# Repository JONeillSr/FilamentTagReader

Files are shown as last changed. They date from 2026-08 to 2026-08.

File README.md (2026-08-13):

# Filament Tag Reader / Writer

An ESP32 + MFRC522 (RC522 / HW-126) reader/writer for **3D-printer filament spool
NFC tags**. It reads and writes multiple tag standards &mdash; **Anycubic**,
**OpenSpool**, and **TigerTag** &mdash; auto-detecting the format on read and
writing whichever format you select. Filament data (type, brand, color,
temperatures, diameter, weight) is shown on a 0.96" SSD1306 OLED and a web
dashboard, and new tags are written from a web form with read-back verification.
A common-cathode tri-color LED and active buzzer give immediate read/write
feedback.

Built from a set of self-contained, application-agnostic modules (board config,
event bus, WiFi provisioning, web service, display, RFID, feedback, and a
pluggable tag-format layer) so each one can be lifted into another ESP32 project
unchanged.

---

## Features

- **Multi-format support** &mdash; reads and writes three filament-tag standards
  through one pluggable interface:
  - **Anycubic** &mdash; the native NTAG21x binary page format (SKU, brand, type,
    color, nozzle/bed temps, diameter, length).
  - **OpenSpool** &mdash; an NDEF/JSON record on NTAG215/216 (type, color, brand,
    single temp range); the simplest cross-tool standard.
  - **TigerTag** &mdash; a big-endian binary structure on NTAG213 using numeric
    material/brand/aspect IDs; read by printers such as the Snapmaker U1.
- **Auto-detect on read** &mdash; tap any tag and the device identifies its format
  (Anycubic header magic, OpenSpool NDEF marker, or TigerTag version field) and
  decodes it. No need to pre-select.
- **Format-aware writes** &mdash; pick the write format on `/setup`; the dashboard
  shows the active format. Writes are read back and **byte-verified** before
  reporting success.
- **Read / write mode** toggled live on the dashboard or set as a persistent
  default on `/setup`.
- **Editable lookup tables** in flash, with browser editors (validated before
  saving, with built-in fallbacks): Anycubic filament definitions (`/filaments`)
  and the TigerTag ID database (`/tigertag`).
- **Color converter** on the write panel: enter HEX, RGB, ABGR, or RGBA and the
  others update live &mdash; each hex form matches the byte order its format
  stores (Anycubic ABGR, TigerTag RGBA).
- **Web dashboard** (`/`) showing all fields, with the filament color rendered
  as a colored circle.
- **Status page** (`/status`) with module health, last UID, write format, and
  last result &mdash; themed, with a dashboard link.
- **WebSerial** (`/webserial`) + telnet (port 23) live diagnostic log &mdash;
  essential because the ESP32-C6 drops USB serial on reboot.
- OTA updates (`/update`) via ElegantOTA.
- WiFi captive-portal provisioning (no hardcoded credentials).
- mDNS: reachable at `http://filament.local`.
- Fully event-driven, FreeRTOS task separation, **no blocking `delay()`**.

---

## Supported boards

Build one environment per board (`platformio.ini`):

| Board | Env | Notes |
|---|---|---|
| Seeed XIAO ESP32-C6 | `xiao_c6` | Primary target. Single I2C bus only. |
| ESP32-C3 devkit | `esp32c3` | Tight GPIO budget. |
| ESP32-S3 devkitc-1 | `esp32s3` | GPIO-rich. |
| Classic ESP32 DevKit | `esp32dev` | Serial survives reboot (watchable). |

```
pio run -e xiao_c6
pio run -e xiao_c6 -t upload
```

Uses the **pioarduino** fork of the espressif32 platform (required for current
ESP32-C6 / Arduino-ESP32 3.x support).

---

## Hardware wiring

OLED is SSD1306, I2C address `0x3C`, on the board's default I2C pins (shared
`Wire` bus &mdash; `Wire1` is avoided per the C6 core bug #10685). RC522 uses
hardware SPI. RGB LED is common-cathode (each leg lit HIGH); active buzzer
sounds when driven HIGH.

Exact GPIO assignments per board live in `src/Pins.h`, chosen to avoid each
board's strapping / flash / USB pins (documented in `lib/BoardConfig`).

### Classic ESP32 DevKit V1 (first bring-up)

Wiring for the `esp32dev` environment, matching the project wiring diagram:

| Function | GPIO | Notes |
|---|---|---|
| OLED SDA | 21 | shared I2C bus |
| OLED SCL | 22 | shared I2C bus |
| RC522 SDA/SS| 17 | VSPI CS |
| RC522 SCK | 18 | VSPI SCK |
| RC522 MOSI  | 23 | VSPI MOSI |
| RC522 MISO  | 19 | VSPI MISO |
| RC522 RST | 4 | plain GPIO |
| Buzzer SPK+ | 13 | SPK- to GND |
| LED Red | 25 | common cathode |
| LED Green | 26 | common cathode |
| LED Blue | 27 | common cathode |

> The RC522 runs on **3.3V** &mdash; it is not 5V-tolerant. If the version
> register reads erratically under load, add a 100&micro;F cap across the
> module's 3.3V / GND pins to absorb inrush.

### XIAO ESP32-C6

| Function | GPIO |
|---|---|
| OLED SDA | 22 |
| OLED SCL | 23 |
| RC522 SCK | 19 |
| RC522 MISO  | 20 |
| RC522 MOSI  | 18 |
| RC522 SS | 17 |
| RC522 RST | 16 |
| Buzzer | 1 |
| LED R | 2 |
| LED G | 21 |
| LED B | 0 |

> See `src/Pins.h` for the C3 / S3 maps.

---

## Tag formats

The device understands three filament-tag standards through a common
`TagFormat` interface. On **read**, each format's detector is tried against the
raw bytes and the matching one decodes; on **write**, the format selected on
`/setup` is used. All three translate to/from one neutral `FilamentRecord`, so
the dashboard, OLED, and feedback are format-independent.

| Format | Chip | Encoding | Detected by |
|---|---|---|---|
| Anycubic  | NTAG21x | binary pages, LE | header magic `0x7B` at page 4  |
| OpenSpool | NTAG215/216 | NDEF + JSON | NDEF record + `openspool` marker |
| TigerTag  | NTAG213 | binary struct, BE | version field at page 4 |

### Anycubic

NTAG21x (4 bytes per page). Multi-byte numbers are **little-endian**; strings are
NUL-padded ASCII across their page range.

| Page  | Example | Field |
|---|---|---|
| 4 | `7B 00 65 00`| header (magic `0x7B` / length) &mdash; not decoded |
| 5&ndash;8 | ASCII  | **SKU** &rarr; `AHPLLB-103` |
| 10&ndash;13 | ASCII  | **Brand** &rarr; `AC` (Anycubic) |
| 15&ndash;18 | ASCII  | **Type** &rarr; `PLA` |
| 20 | `FF 00 FF 00`| **Color**, ABGR byte order &rarr; `#00FF00` |
| 24 | `C8 00 D2 00`| **Extruder temp** min/max &rarr; 200&ndash;210 &deg;C |
| 29 | `32 00 3C 00`| **Bed temp** min/max &rarr; 50&ndash;60 &deg;C |
| 30 | `AF 00 4A 01`| **Diameter** (`175`/100 = 1.75 mm), **Length** raw `330` |
| 31 | `E8 03 00 00`| unknown (`1000`) &mdash; not decoded |

**Color note:** page 20 is decoded as ABGR (bytes A, B, G, R). The example
`FF 00 FF 00` therefore yields R=0, G=255, B=0 = **green `#00FF00`**, *not*
magenta. If real spools show the wrong swatch, the byte order is the first
thing to revisit.

**Length note:** `lengthRaw` (e.g. `330`) is surfaced raw; its exact units
(meters vs a packed value) are unconfirmed and shown as-is.

Writing touches only the pages this format defines (4, 5&ndash;8, 10&ndash;13,
15&ndash;18, 20, 24, 29&ndash;31); lock and configuration pages are left
untouched.

### OpenSpool

A single NDEF record of MIME type `application/json` on NTAG215/216, wrapped in
the NTAG NDEF-message TLV. The payload is human-readable:

```
{ "protocol":"openspool", "version":"1.0", "type":"PLA",
  "color_hex":"FFAABB", "brand":"Generic",
  "min_temp":"220", "max_temp":"240" }
```

Brands are constrained to the OpenSpool set (Generic, Overture, PolyLite, eSun,
PolyTerra); unknown brands write as `Generic`. OpenSpool carries a single
(nozzle) temp range; bed temps are not part of the standard.

### TigerTag

A fixed **big-endian** binary structure on NTAG213, pages 4&ndash;23 (80 bytes);
pages 24&ndash;39 hold an optional ECDSA signature that this firmware does not
read or write (basic read/write scope). Material, brand, and finish ("aspect")
are stored as **numeric IDs** from the TigerTag database rather than text.

| Bytes (from page 4) | Field |
|---|---|
| 0&ndash;3 | ID TigerTag (format/version) |
| 4&ndash;7 | ID Product (`FFFFFFFF` for Maker tags) |
| 8&ndash;9 | Material ID |
| 10 | Diameter ID (`0x38`=1.75, `0xDD`=2.85) |
| 11&ndash;12 | Aspect 1 / 2 (finish) |
| 13 | Type (`0x8E`=Filament) |
| 14&ndash;15 | Brand ID |
| 16 | Unit (`0x15`=g) |
| 17&ndash;20 | Color1 RGBA |
| 29&ndash;31 | Weight (grams) |
| 32&ndash;37 | Nozzle min/max, dry temp/time, bed min/max |
| 38&ndash;41 | Timestamp (also twin-tag pairing ID) |
| 54&ndash;79 | Custom message (up to 26 bytes) |

The numeric IDs are resolved via `data/tigertag_ids.json` (the official TigerTag
database, brand/material/aspect &rarr; ID), with an alias layer that maps common
local naming (e.g. `Matte` &rarr; `Matt`, `PLA` + `High Speed` &rarr; the
`PLA High Speed` material) onto the official IDs. Brands not in the database
write as Generic, with the real brand name kept in the custom-message field.

> **Note:** implemented purely from the public TigerTag specification (not their
> GPLv3 code) to keep this project's MIT license clean. "TigerTag" is referenced
> only as a supported format name, per their trademark policy.

All three codecs are **bidirectional**: a tag written by this device reads back
identically, and each `encode()` is the inverse of its `decode()`.

---

## Reading and writing

The device runs in one of two modes, shown in the dashboard header:

- **Read** (default) &mdash; a tap auto-detects the tag's format and shows the
  decoded spool (including which format it was) on the OLED and dashboard.
- **Write** &mdash; the **Write a spool tag** panel appears (with the active
  write format shown as a badge). Pick a material, color, and weight, then
  **Write tag** and tap. The device encodes the record in the selected format,
  writes it, reads it back, and only reports success if every written page
  verifies.

Toggle the mode live from the dashboard, or set a persistent power-on default on
`/setup`. The **write format** (Anycubic / OpenSpool / TigerTag) is also chosen
on `/setup` and shown on `/status`. Material temps and brand are filled in
automatically for the chosen material; color comes from the picker; weight maps
to the format's weight/length field.

### Color converter

The write panel includes a four-way color converter: enter a value as **HEX**,
**RGB**, **ABGR**, or **RGBA** and the others update live; picking a color in the
color picker updates the boxes too. Each hex form uses the byte order its format
stores &mdash; ABGR for Anycubic, RGBA for TigerTag &mdash; so it doubles as a
tool for cross-checking raw tag bytes. **Use** sets the write color from the
converter.

### Lookup tables

Two editable JSON tables live in the flash filesystem:

- **`data/filaments.json`** (editable at **`/filaments`**) &mdash; Anycubic
  material definitions: extruder/bed temps, SKU, brand, and a weight&rarr;length
  map.
- **`data/tigertag_ids.json`** (editable at **`/tigertag`**) &mdash; the TigerTag
  brand/material/aspect ID database plus the local-naming alias layers.

Both have a browser editor (linked from the dashboard header) with the same
validated-save behavior. Edits are written straight to LittleFS, so adding a
brand or fixing a mapping no longer needs a re-flash.

Edits are validated before saving &mdash; malformed JSON is rejected and the
previous table kept &mdash; and small built-in fallback sets are used if a file
is missing or invalid (the fallback state is surfaced on `/status`).

### Read / write feedback

| Outcome | LED | Buzzer |
|---|---|---|
| Good read | green | two short beeps |
| Good write | blue  | two short beeps |
| Bad read/write | red | one long beep |

The OLED "Write OK" screen also shows which format was written.

> A hardware mode button is a planned option; for now the mode is set from the
> web UI.

---

## Architecture

Event-driven with FreeRTOS task separation. In read mode the reader task decodes
a tag and pushes an `AppEvent`; in write mode it writes the queued record and
verifies it, pushing a write-result event. A dispatcher task consumes the queue
and updates the OLED, LED/buzzer, and logs.

```
[RFIDReader task] read mode  --detect+decode--> FilamentTag store (mutex)
                  write mode --encode+write+verify-->
        |          (via the selected/auto-detected TagFormat)
        +-----> appEventQueue ---------+
                       |   EVT_FILAMENT_READ / EVT_TAG_ERROR
                       |   EVT_TAG_WRITTEN  / EVT_WRITE_ERROR
                       v
              [dispatcher task]  -> OLED / LED / buzzer / webserial log

[WebService task]   /  /api/filament  /api/write  /api/materials  /filaments  /tigertag
                    /status  /setup  /update  /webserial
[WiFiManager task]  captive portal (AP) or STA reconnect
[Feedback task]     non-blocking LED + buzzer timing
```

The reader is format-agnostic: a `TagFormatRegistry` holds the known formats,
detects the right one on read, and supplies the selected one on write. Adding a
new standard means writing one more `TagFormat` &mdash; nothing else changes.

### Modules

Reusable (`lib/`, app-agnostic, shared across projects):

| Module | Responsibility |
|---|---|
| `BoardConfig` | Per-chip facts: I2C defaults, USB/Wire1 flags, strapping. |
| `Events` | App-wide event bus types + `appEventQueue`. |
| `WiFiManager` | NVS credentials, captive-portal provisioning, mDNS, optional NTP time sync. |
| `WebService`  | `/status`, `/setup` (incl. a **Reboot device** button), `/update` (OTA), `/webserial`, telnet.|
| `DeviceIdentity`| MAC-derived device ID + mDNS hostname unique per unit + location labels. Shared with RFID_Access; available here but not yet wired in. |
| `Display` | App-agnostic SSD1306 helper: status/message screens, header band, `raw()`. Caller owns the I2C bus. No project dependencies; identical to RFID_Access's copy. |
| `RFIDReader`  | MFRC522 wrapper + reader task; reads (auto-detect) **and** writes/verifies via the selected format; emits events. |
| `FilamentTag` | Anycubic NTAG codec (`decode`/`encode`) + the neutral `FilamentRecord` + mutex-guarded last record. |
| `FilamentDB`  | JSON-backed Anycubic filament definitions (temps/SKU/brand/weights) with validation + fallback. Lives with `FilamentTag`. |
| `TagFormat` | Pluggable format layer: `TagFormat` interface, `TagFormatRegistry`, and the `Anycubic` / `OpenSpool` / `TigerTag` implementations + `TigerTagDB` (ID lookups). |
| `DeviceSettings`| NVS-backed settings (splash holds, hostname, default mode, write format). |
| `Feedback` | Non-blocking RGB LED + active buzzer cues (read/write/error). |

Project-specific (`src/`):

| File | Responsibility |
|---|---|
| `Pins.h` | Per-board peripheral pin map (board-guarded). |
| `FilamentScreen.h`| Project OLED screens — decoded filament record, "Scan tag" idle prompt, tag-error screen; all draw on `Display::raw()` (keeps `Display` app-agnostic). |
| `HtmlPages.h` | Dashboard (read view + write form + color converter), `/filaments` and `/tigertag` editors (PROGMEM). |
| `WebHandlers.*` | `/`, `/api/filament`, `/api/write`, `/api/mode`, `/api/materials`, `/api/db` + `/filaments`, `/api/ttdb` + `/tigertag`. |
| `main.cpp` | Wiring, format registration, and the event dispatcher. |

---

## Diagnostics

Because the **ESP32-C6 drops USB serial on reboot** (boot messages scroll past
before the monitor reconnects), all important logging is mirrored to:

- the **OLED** during startup (each subsystem reports OK/FAIL),
- **`/webserial`** and **telnet :23** once WiFi is up,
- plus `Serial` (watchable on the classic ESP32, which uses an external
  USB-UART).

The **`/status`** and **`/webserial`** pages refresh their content by polling a
small text endpoint (`/status.txt`, `/webserial.txt`) and swapping only the
changing block, rather than reloading the whole page. This keeps the header and
the (separately fetched) footer from flickering on every update, and cuts the
per-refresh payload to a few hundred bytes. The initial content is still
server-rendered into the page, so both work with JavaScript disabled &mdash; they
just stop live-updating.

---

## Build notes

- Uses the **pioarduino** `stable` platform URL, which tracks the latest tested
  ESP32 Arduino 3.x release. If you pin an old tagged version instead and PlatformIO
  reports `MissingPackageManifestError: Could not find one of 'package.json'`,
  the pinned version is stale or its cached download is corrupt: clear it with
  `pio system prune --force` (and delete the stale folder under
  `<core_dir>/platforms/`), then rebuild to re-fetch.
- `board_build.partitions = min_spiffs.csv` &mdash; buys app flash space for
  WiFi + web + OTA. Still leaves ~190&nbsp;KB of filesystem, ample for the lookup
  tables (Anycubic filaments ~2&nbsp;KB + TigerTag ID database ~18&nbsp;KB).
- `board_build.filesystem = littlefs` &mdash; the lookup tables live as JSON
  files on **LittleFS** (more robust than SPIFFS, better power-loss behavior).
  **Upload the filesystem before the firmware** so the tables exist on first
  boot:

  ```
  pio run -e esp32dev -t uploadfs    # uploads data/ (filaments.json + tigertag_ids.json)
  pio run -e esp32dev -t upload      # uploads firmware
  ```

  If the filesystem is never uploaded, each format falls back to a small
  built-in table (and says so on `/status`). Re-run `uploadfs` after editing a
  table file locally.
- `ELEGANTOTA_USE_ASYNC_WEBSERVER=0` &mdash; ElegantOTA runs on the sync
  `WebServer` that `WebService` owns (no ESPAsyncWebServer dependency).
- **Async libraries are intentionally blocked.** This project is sync-only, but
  ElegantOTA's manifest *declares* `AsyncTCP` and `ESPAsyncWebServer` as
  dependencies. If the Library Dependency Finder is allowed to pull them in
  (e.g. under `lib_ldf_mode = deep`/`deep+`), they fail to compile against the
  Arduino-ESP32 3.x core with `fatal error: Network.h` /
  `NetworkInterface.h: No such file or directory`. The build flag alone does
  not prevent this &mdash; it only changes which headers ElegantOTA's own source
  includes, not which libraries the finder compiles. Two settings keep them
  out: `lib_ldf_mode = chain` (does not crawl third-party manifests) and an
  explicit `lib_ignore` for both async libraries. If you ever see those missing
  `Network.h` errors, that async stack got pulled in somewhere &mdash; check
  both settings.

---

## License

MIT &mdash; AWS Solutions LLC dba Azure Innovators.

---

## Changelog

- **v1.3** &mdash; **Shared-library parity with RFID_Access.** Every reusable
  module (`Display`, `WebService`, `WiFiManager`, `DeviceSettings`,
  `SplashScreen`, `DeviceIdentity`) is now byte-identical across both projects.
  - `Display` consolidated onto one implementation: the driver is a member
    rather than a heap-allocated file-static singleton (so `raw()` can no longer
    dereference null, and a project may hold more than one panel), and the
    **caller now owns the I2C bus**. That last change fixes a real latent bug —
    this project previously let Adafruit's `begin()` re-initialise `Wire` with no
    pin arguments, which silently moves the bus back to the core's variant
    defaults. It only worked because the configured pins happened to match.
  - Filament-specific screens (`showWaiting`, `showError`) moved out of
    `Display` into `FilamentScreen`, where the project's other screens already
    live; the unused `showSplash` was removed.
  - `WebService` gained a **Reboot device** button on `/setup` (POST-only) and
    proper attribute escaping, so an apostrophe in a saved value can no longer
    corrupt the settings form.
  - `WiFiManager` gained optional NTP time sync (opt-in; no behavior change
    unless `setTimeSync()` is called).
- **v1.2** &mdash; **Multi-format support.** Added a pluggable `TagFormat` layer
  (`TagFormat` interface + `TagFormatRegistry`) with three formats: **Anycubic**
  (refactored behind the interface, no behavior change), **OpenSpool**
  (NDEF/JSON on NTAG215/216), and **TigerTag** (big-endian binary on NTAG213
  with numeric IDs via `TigerTagDB` + `data/tigertag_ids.json`). Reads
  auto-detect the format; writes use the format chosen on `/setup` (shown on the
  dashboard, `/status`, and the OLED write screen). Added a four-way HEX/RGB/
  ABGR/RGBA color converter to the write panel (synced to the color picker).
  Both lookup tables (`/filaments`, `/tigertag`) have browser editors with
  validated saves straight to LittleFS. Themed `/status` and `/webserial` pages with a dashboard link and shared
  footer, refreshing via content polling (`/status.txt`, `/webserial.txt`) so
  the footer no longer flickers. Read views (dashboard + OLED) show the detected
  format; OLED read layout reworked (per-field lines, no swatch). Renamed the
  device to "Filament Tag Reader". Minor dashboard fixes (last-read hidden in
  write mode, clearer labels, readable mode toggle, "Write tag" button); removed
  the misleading "external" arrow on the footer's Firmware-update link.
  Decoupled `Display` from the filament codec: the record screen moved to a
  project-side `FilamentScreen` helper drawing on `Display::raw()`, so `Display`
  now depends only on Adafruit_SSD1306 and drops into any project unchanged.
- **v1.1** &mdash; Combined reader/**writer**: write spool tags from the
  dashboard (material/color/weight) with read-back verification; live read/write
  mode toggle + persistent default on `/setup`; bidirectional `FilamentTag`
  codec (`encode` added); new `FilamentDB` JSON-backed, web-editable filament
  tables (`/filaments`) with validation and built-in fallback; blue/green/red
  LED + beep cues for write/read/error; migrated filesystem to LittleFS.
- **v1.0** &mdash; Initial: NTAG decode, OLED + web dashboard with color circle,
  LED/buzzer feedback, WebSerial diagnostics, OTA, four board environments.

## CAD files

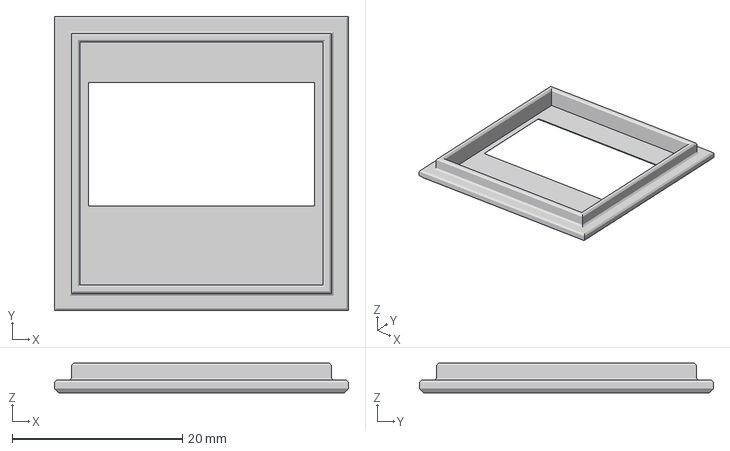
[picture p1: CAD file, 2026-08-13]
enclosure/OLED Cover.3mf
34.5 x 34.5 x 3.50 mm

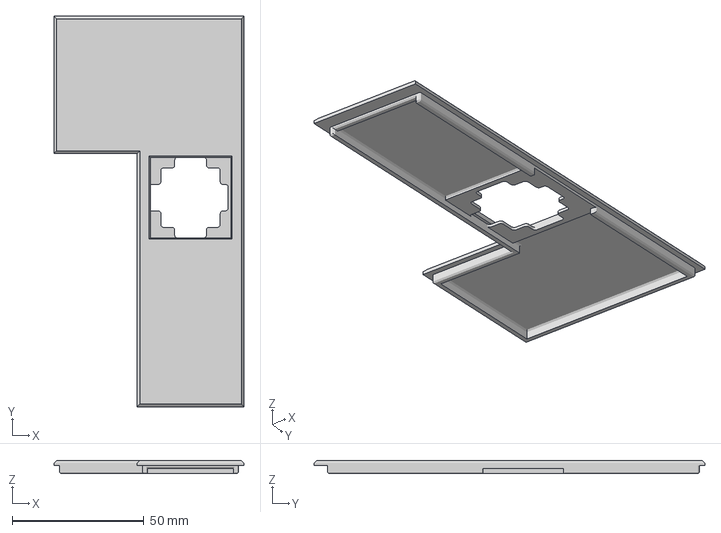
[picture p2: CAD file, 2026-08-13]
enclosure/Lid.3mf
72.0 x 148.0 x 5.00 mm

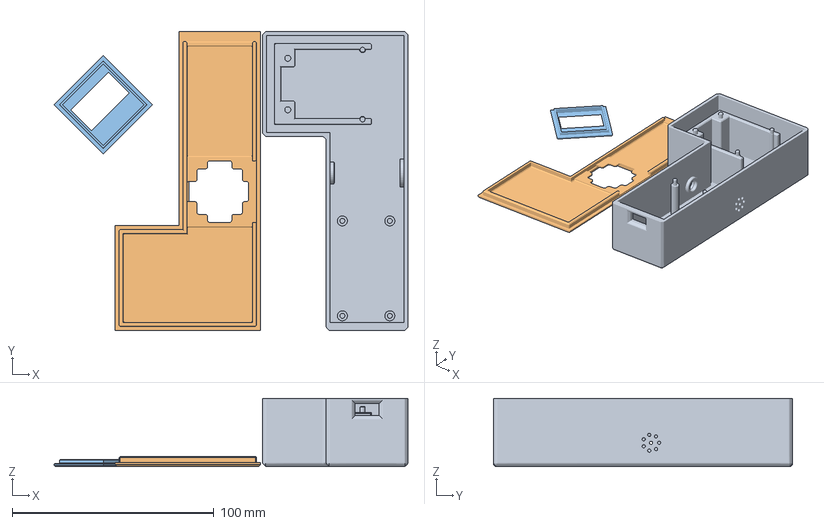
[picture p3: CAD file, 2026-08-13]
enclosure/Enclosure.3mf
175.3 x 148.0 x 33.8 mm
Base
Lid
OLED Cover

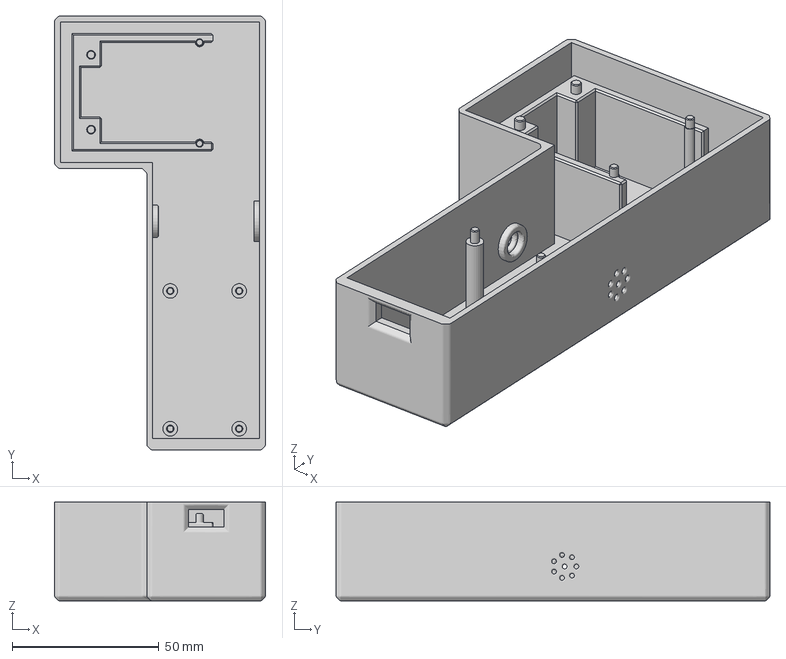
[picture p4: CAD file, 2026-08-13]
enclosure/Base.3mf
72.0 x 148.0 x 33.8 mm

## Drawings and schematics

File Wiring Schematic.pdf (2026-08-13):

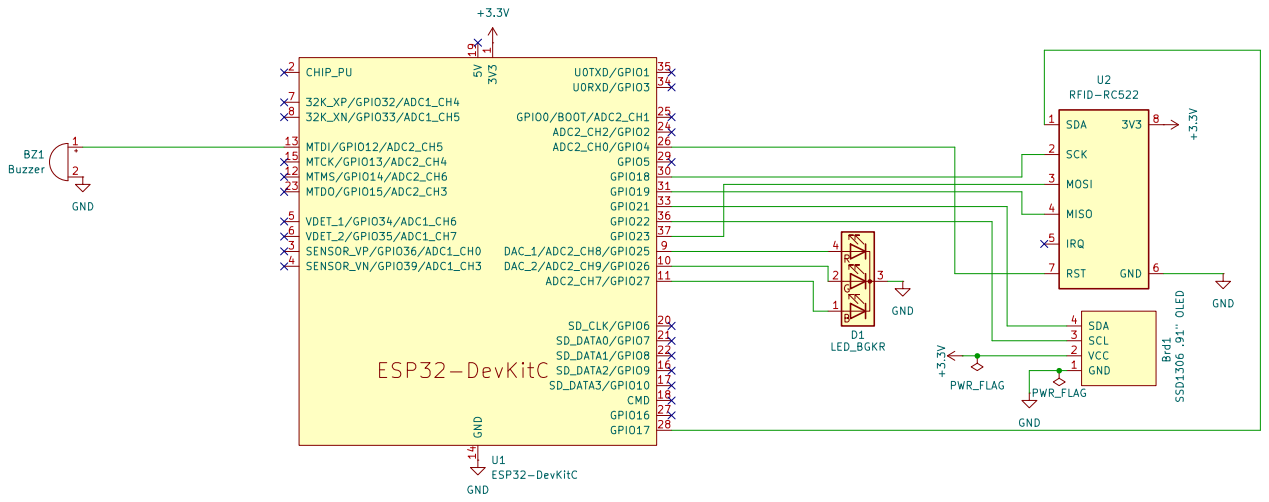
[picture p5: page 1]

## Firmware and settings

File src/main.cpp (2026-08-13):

/**
 * @file    main.cpp
 * @brief   Filament Tag Reader / Writer - top-level wiring and event dispatcher.
 *
 * Architecture (event-driven, FreeRTOS task separation):
 *
 *   [RFIDReader task] --reads & decodes a tag--> pushes AppEvent
 *        |                                              |
 *        v                                              v
 *   FilamentTag store (mutex)                     appEventQueue
 *                                                        |
 *                                                        v
 *                                          [dispatcher task in main]
 *                                          - updates OLED
 *                                          - drives LED/buzzer cues
 *                                          - logs to /webserial + Serial
 *
 *   [WebService task]  serves /, /api/filament, /status, /update, /webserial
 *   [WiFiManager task] portal (AP) OR STA reconnect housekeeping
 *   [Feedback task]    non-blocking LED/buzzer timing
 *
 * Nothing here blocks: every wait is vTaskDelay. The C6 drops USB serial on
 * reboot, so all startup progress is mirrored to the OLED and (once WiFi is up)
 * to /webserial and telnet.
 */

#include <Arduino.h>
#include "Pins.h"
#include "BoardConfig.h"
#include "Events.h"
#include "FilamentTag.h"
#include "FilamentDB.h"
#include "TagFormatRegistry.h"
#include "AnycubicFormat.h"
#include "OpenSpoolFormat.h"
#include "TigerTagDB.h"
#include "TigerTagFormat.h"
#include "RFIDReader.h"
#include "Display.h"
#include "FilamentScreen.h"
#include "Feedback.h"
#include "WiFiManager.h"
#include "WebService.h"
#include "WebHandlers.h"
#include "DeviceSettings.h"
#include "SplashScreen.h"
#include "AWSBitmap.h"      // project-specific boot logo data (src/)

// ---- Globals ---------------------------------------------------------------
QueueHandle_t appEventQueue = nullptr;   // defined here (declared extern in Events.h)

// Subsystems.
// Display takes panel geometry; the I2C bus is the caller's to start (see
// setup()), so the panel can share it and get board-specific bus setup.
static Display       display(OLED_WIDTH, OLED_HEIGHT, -1);
static Feedback      feedback(LED_R_PIN, LED_G_PIN, LED_B_PIN, BUZZER_PIN,
                              RGB_LED_ACTIVE_HIGH);
static RFIDReader    reader(RC522_SS_PIN, RC522_RST_PIN,
                            RC522_SCK_PIN, RC522_MISO_PIN, RC522_MOSI_PIN);
static WiFiManager   wifi("FilamentReader-Setup");   // captive-portal AP SSID
static WebService    web(80);
static DeviceSettings settings;                       // NVS-backed settings store
static FilamentDB    filamentDb;                      // JSON-backed filament tables

// Pluggable tag formats. Stage 1 registers only Anycubic, so behavior is
// unchanged; OpenSpool joins the registry in the next stage.
static TagFormatRegistry tagFormats;
static AnycubicFormat    anycubicFormat;
static OpenSpoolFormat   openSpoolFormat;
static TigerTagDB        tigerTagDb;                  // TigerTag ID lookup tables
static TigerTagFormat    tigerTagFormat(&tigerTagDb);

static const char* HOSTNAME = "filament";          // http://filament.local

// ---- Dispatcher: consumes appEventQueue ------------------------------------
static void dispatcherTask(void* pv) {
    AppEvent ev;
    for (;;) {
        // Block until an event arrives (no busy-wait, no delay()).
        if (xQueueReceive(appEventQueue, &ev, portMAX_DELAY) != pdTRUE) continue;

        switch (ev.type) {
            case EVT_FILAMENT_READ: {
                FilamentRecord rec = FilamentTag::storeGet();
                feedback.cueSuccess();
                if (display.isReady())
                    FilamentScreen::show(display.raw(), rec, reader.lastReadFormat());
                web.log("[evt] filament read OK uid=" + String(ev.filament.uid) +
                        " sku=" + String(rec.sku) +
                        " type=" + String(rec.type) +
                        " color=" + String(rec.colorHex));
                break;
            }
            case EVT_TAG_ERROR: {
                feedback.cueError();
                if (display.isReady())
                    FilamentScreen::error(display.raw(), String(ev.filament.uid),
                                          "code " + String(ev.filament.errorCode));
                web.log("[evt] tag error uid=" + String(ev.filament.uid) +
                        " code=" + String(ev.filament.errorCode));
                break;
            }
            case EVT_TAG_WRITTEN: {
                // Blue + double beep = good verified write.
                feedback.cueWrite();
                display.showStatus("Write OK", "Tag written +",
                                   "verified", reader.writeFormatName());
                web.log("[evt] tag WRITE verified uid=" + String(ev.filament.uid) +
                        " fmt=" + reader.writeFormatName());
                break;
            }
            case EVT_WRITE_ERROR: {
                // Red + long beep = bad write/verify.
                feedback.cueError();
                if (display.isReady())
                    FilamentScreen::error(display.raw(),
                                          String(ev.filament.uid), "write failed");
                web.log("[evt] tag WRITE failed uid=" + String(ev.filament.uid));
                break;
            }
            case EVT_CARD_TAP:
            default:
                break;   // not used in this project
        }
    }
}

// ---- WiFi status callbacks (mirror to OLED for the headless C6) -------------
static void onWifiConnected() {
    // Use the saved hostname if the user set one in /setup; else the default.
    String host = settings.hostname(HOSTNAME);
    web.setHostname(host);
    registerWebHandlers(web.routes(), reader, filamentDb, tigerTagDb);   // project routes BEFORE begin()
    // Enable the reusable /setup page (splash hold, diagnostics hold, board,
    // hostname). This project adds no project-specific setup fields yet; when it
    // does, call web.setSetupFieldsProvider()/setSetupSaveHandler() here.
    web.enableSetup(&settings);

    // Add a persistent read/write mode toggle to the /setup page. The dashboard
    // also has a runtime toggle; this one is the saved default applied on boot.
    web.setSetupFieldsProvider([](String& html) {
        bool wm = settings.getBool("mode_write", false);
        html += "<label>Default mode"
                "<select name=\"mode_write\">";
        html += String("<option value=\"0\"") + (!wm ? " selected" : "") + ">Read</option>";
        html += String("<option value=\"1\"") + ( wm ? " selected" : "") + ">Write</option>";
        html += "</select></label>";

        // Write format selector, built from the registered formats so it stays
        // in sync as formats are added. Reads always auto-detect; this only sets
        // which format new tags are written in.
        String cur = settings.getString("write_format", "anycubic");
        html += "<label>Write format"
                "<select name=\"write_format\">";
        for (auto* f : tagFormats.all()) {
            bool sel = (cur == f->id());
            html += String("<option value=\"") + f->id() + "\"" +
                    (sel ? " selected" : "") + ">" + f->name() + "</option>";
        }
        html += "</select></label>";
    });
    web.setSetupSaveHandler([](WebServer& s) {
        if (s.hasArg("mode_write")) {
            bool wm = (s.arg("mode_write") == "1");
            settings.setBool("mode_write", wm);
            reader.setMode(wm ? RFIDReader::Mode::Write : RFIDReader::Mode::Read);
        }
        if (s.hasArg("write_format")) {
            String wf = s.arg("write_format");
            settings.setString("write_format", wf);
            reader.setWriteFormat(tagFormats.byId(wf.c_str()));
        }
    });
    web.setStatusProvider([](String& body) {
        // Project-specific lines appended to the common /status block.
        body += "Board:    " BOARD_NAME "\n";
        body += "OLED:     " + String(display.isReady() ? "OK" : "FAIL") + "\n";
        body += "WriteFmt: " + settings.getString("write_format", "anycubic") + "\n";
        body += "Reader:   " + String(reader.isReaderPresent() ? "OK" : "OFFLINE") + "\n";
        body += "Reads:    " + String(reader.readCount()) + "\n";
        body += "Last UID: " + reader.lastUid() + "\n";
        body += "Last res: " + String(reader.lastReadOk() ? "OK" : "ERROR") + "\n";
        if (FilamentTag::storeHasData()) {
            FilamentRecord r = FilamentTag::storeGet();
            body += "Filament: " + String(r.brand) + " " + String(r.type) +
                    " " + String(r.colorHex) + "\n";
        }
    });
    // Footer theme: the dashboard uses the green accent (#5fd3a0) with a muted
    // separator, matching the rest of this project's UI. The built-in links
    // (Device status / Device log / Firmware update) are auto-added by the
    // module; this project has no extra pages, so no addFooterLink() is needed.
    web.setFooterColors("#5fd3a0", "#2a3645", "#7fe0b5");
    web.begin();
    if (display.isReady())
        FilamentScreen::waiting(display.raw(), wifi.localIP().toString());
    web.log("[net] connected, web up at http://" + wifi.localIP().toString());
}

static void onProvisioning() {
    display.showStatus("WiFi setup", "Join AP:",
                       "FilamentReader-Setup", "then open 192.168.4.1");
}

// ===========================================================================
void setup() {
    Serial.begin(115200);            // mirrored, but unwatchable on C6 reboot

    // The event queue must exist before any producer/consumer task starts.
    appEventQueue = xQueueCreate(8, sizeof(AppEvent));
    FilamentTag::storeInit();

    // Settings store first, so the saved splash hold (and other settings) are
    // available before we play the boot splash.
    settings.begin("filament");

    // Filament definition tables (JSON in LittleFS, with built-in fallback). A
    // missing or malformed file falls back to a small built-in set, surfaced on
    // /status. Loaded before web routes so /api/materials has data immediately.
    bool dbOk = filamentDb.begin("/filaments.json");
    web.log(String("[db] filament tables ") +
            (dbOk ? "loaded" : "FELL BACK to built-in") +
            (filamentDb.usingFallback() ? " (fallback)" : ""));

    // TigerTag ID lookup tables (brands/materials/aspects -> numeric IDs).
    bool ttOk = tigerTagDb.begin("/tigertag_ids.json");
    web.log(String("[db] tigertag IDs ") +
            (ttOk ? "loaded" : "FELL BACK to built-in") +
            (tigerTagDb.usingFallback() ? " (fallback)" : ""));

    // OLED first: it is our boot diagnostic surface.
    //
    // The caller owns the bus. Bring it up explicitly on the configured pins,
    // slow it down, and let the panel's internal supply settle before pushing
    // the init sequence. Display::begin() then passes periphBegin=false so
    // Adafruit's begin() cannot re-init Wire with no pin arguments and silently
    // move the bus back to the core's variant defaults.
    Wire.begin(OLED_SDA_PIN, OLED_SCL_PIN);
    Wire.setClock(100000);            // gentle, reliable
    delay(100);                       // let the panel's supply settle
    bool oledOk = display.begin(Wire, OLED_ADDR);

    // ---- Phase 1: animated boot splash, held for the configured time -------
    // The splash animates once, then stays visible for splashHoldSec. The hold
    // here uses vTaskDelay (not delay()), so it never blocks other cores/tasks;
    // at this point in setup() no app tasks depend on the screen yet.
    uint16_t splashSec = settings.splashHoldSec(5);   // default 5 s
    uint16_t diagSec   = settings.diagHoldSec(3);     // default 3 s
    if (oledOk) {
        SplashScreen splash(display.raw(), AWS_LOGO, AWS_LOGO_W, AWS_LOGO_H,
                            AWS_LOGO_REST_Y);
        splash.playAnimation();                       // runs once, before tasks
        if (splashSec) vTaskDelay(pdMS_TO_TICKS((uint32_t)splashSec * 1000UL));
    }

    // Phase 2 begins below: the per-subsystem boot diagnostics are drawn as
    // each subsystem comes up, then held for diagSec before live data. We bring
    // the subsystems up first (so the final diagnostics screen is complete),
    // then apply the diagnostics hold just before starting WiFi/live UI.

    // Feedback (LED/buzzer) up early so cues work immediately.
    feedback.begin();
    feedback.cueScan();              // blue blip = alive

    // RFID reader. Logger routes through WebService::log so lines also reach
    // /webserial + telnet (once WiFi is up); before that they go to Serial.
    reader.setLogger([](const String& s) { web.log(s); });

    // Register known tag formats and wire them into the reader. Reads
    // auto-detect among all registered formats; the write format is chosen on
    // /setup (default Anycubic).
    tagFormats.add(&anycubicFormat);
    tagFormats.add(&openSpoolFormat);
    tagFormats.add(&tigerTagFormat);
    reader.setFormatRegistry(&tagFormats);
    {
        String wf = settings.getString("write_format", "anycubic");
        reader.setWriteFormat(tagFormats.byId(wf.c_str()));
    }

    bool readerOk = reader.begin(appEventQueue);

    // Restore the saved read/write mode (set on /setup). Default is read.
    bool writeMode = settings.getBool("mode_write", false);
    reader.setMode(writeMode ? RFIDReader::Mode::Write : RFIDReader::Mode::Read);

    // ---- Phase 2: boot diagnostics, held for the configured time -----------
    // Final per-subsystem status screen. Held for diagSec so it is readable on
    // the headless C6 (USB serial is gone by now), then Phase 3 (live data via
    // onWifiConnected -> showWaiting) replaces it.
    display.showStatus("Booting...",
                       String("Board: ") + BOARD_NAME,
                       String("OLED: ") + (oledOk ? "OK" : "FAIL"),
                       String("RC522: ") + (readerOk ? "OK" : "FAIL"));
    if (diagSec) vTaskDelay(pdMS_TO_TICKS((uint32_t)diagSec * 1000UL));

    // Event dispatcher.
    xTaskCreate(dispatcherTask, "dispatch", 4096, nullptr, 1, nullptr);

    // WiFi: register callbacks, then begin(). begin() either connects (STA) and
    // fires onConnected, or starts the provisioning AP and fires onProvisioning.
    wifi.setHostname(HOSTNAME);
    wifi.onConnected(onWifiConnected);
    wifi.onProvisioningStarted(onProvisioning);
    wifi.begin();
}

void loop() {
    // Only WiFiManager housekeeping lives here; everything else is task-driven.
    wifi.loop();
    vTaskDelay(pdMS_TO_TICKS(50));   // yield; never delay()
}

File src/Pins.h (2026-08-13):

/**
 * @file    Pins.h
 * @brief   Project peripheral pin map for the Filament Tag Reader / Writer.
 *
 * This header answers "where is each peripheral wired for THIS project?" — the
 * RC522 SPI bus, the active buzzer, and the common-cathode tri-color LED. It
 * deliberately holds no board-identity facts; those come from BoardConfig.h
 * (I2C defaults, native-USB flag, strapping warnings). We include BoardConfig
 * here so the OLED can fall back to the board's known-good I2C pins.
 *
 * Pin choices deliberately avoid the strapping / flash / USB GPIOs documented
 * in BoardConfig.h for each board. Where a board has tight GPIO budget (C3),
 * pins are chosen from the remaining safe set.
 *
 * The OLED is a 0.96" SSD1306 two-color unit at I2C address 0x3C, sharing the
 * single Wire bus (Wire1 is avoided per the C6 core bug).
 *
 * Exactly one BOARD_* flag must be defined in platformio.ini (BoardConfig.h
 * enforces this with an #error).
 */

#ifndef PINS_H
#define PINS_H

#include "BoardConfig.h"

// ---- OLED (SSD1306, 0x3C, shared Wire bus) ---------------------------------
// Use the board's vetted default I2C pins from BoardConfig.h. All I2C devices
// share one bus on these pins (single-bus rule from the C6 Wire1 bug).
#define OLED_SDA_PIN   BOARD_I2C_SDA_DEFAULT
#define OLED_SCL_PIN   BOARD_I2C_SCL_DEFAULT
#define OLED_ADDR      0x3C
#define OLED_WIDTH     128
#define OLED_HEIGHT    64

// ============================================================================
//  Per-board peripheral assignments
//  RC522 uses hardware SPI (SCK/MISO/MOSI) + SS + RST. Buzzer is a single
//  digital output. RGB LED is three digital outputs (common cathode => drive
//  HIGH to light each leg).
// ============================================================================

#if defined(BOARD_XIAO_ESP32C6)
    // XIAO C6: SPI on the labeled SPI header. GPIO1 is a plain GPIO here (not a
    // strapping, flash, or USB pin per BoardConfig.h), so it is safe as a
    // general-purpose output. Avoid the strapping pins 4, 5, 8, 9, 15.
    #define RC522_SCK_PIN    19   // XIAO "SCK"
    #define RC522_MISO_PIN   20   // XIAO "MISO"
    #define RC522_MOSI_PIN   18   // XIAO "MOSI"
    #define RC522_SS_PIN     17   // XIAO "SS" / D7
    #define RC522_RST_PIN    16   // XIAO D6
    #define BUZZER_PIN        1    // plain GPIO (not strapping/flash/USB)
    #define LED_R_PIN         2
    #define LED_G_PIN         21
    #define LED_B_PIN         23   // NOTE: shares default SCL slot conceptually;
                                   // OLED SCL default is 23 -> see override below

// ============================================================================
#elif defined(BOARD_ESP32C3)
    // C3 has a tight safe-GPIO budget. Flash: 12-17. USB-JTAG: 18,19.
    // Strapping: 2,8,9. Remaining usable: 0,1,3,4,5,6,7,10,20,21.
    #define RC522_SCK_PIN    4
    #define RC522_MISO_PIN   5
    #define RC522_MOSI_PIN   6
    #define RC522_SS_PIN     7
    #define RC522_RST_PIN    10
    #define BUZZER_PIN        3
    #define LED_R_PIN         0
    #define LED_G_PIN         1
    #define LED_B_PIN         20

// ============================================================================
#elif defined(BOARD_ESP32S3)
    // S3 is GPIO-rich. Avoid strapping 0,3,45,46; flash/PSRAM 26-37; USB 19,20.
    #define RC522_SCK_PIN    12
    #define RC522_MISO_PIN   13
    #define RC522_MOSI_PIN   11
    #define RC522_SS_PIN     10
    #define RC522_RST_PIN    14
    #define BUZZER_PIN        4
    #define LED_R_PIN         5
    #define LED_G_PIN         6
    #define LED_B_PIN         7

// ============================================================================
#elif defined(BOARD_ESP32DEV)
    // Classic ESP32. Avoid strapping 0,2,5,12,15; flash 6-11; input-only 34-39.
    // GPIO17 is the correct SS choice (GPIO12 strapping would block boot).
    #define RC522_SCK_PIN    18   // VSPI SCK
    #define RC522_MISO_PIN   19   // VSPI MISO
    #define RC522_MOSI_PIN   23   // VSPI MOSI
    #define RC522_SS_PIN     17   // safe SS (NOT 5/12)
    #define RC522_RST_PIN     4   // plain GPIO, safe as a reset output
    #define BUZZER_PIN       13
    #define LED_R_PIN        25
    #define LED_G_PIN        26
    #define LED_B_PIN        27

#else
    #error "Pins.h: no known BOARD_* defined. Set one in platformio.ini build_flags."
#endif

// ---- RGB LED polarity ------------------------------------------------------
// Common-cathode LED: each color leg lights when driven HIGH. If you wire a
// common-anode part instead, flip this to 0 and the LED helper inverts.
#define RGB_LED_ACTIVE_HIGH   1
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

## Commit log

2026-08-18 Sync shared libraries from RFID_Access
    Six libraries are hand-synced between the two projects and are kept
    byte-identical. The files on disk matched, but this repo's history had fallen
    several syncs behind, so these changes were live here without ever being
    recorded.
    WebService
    Log lines store the UTC epoch rather than a formatted string, and are
    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
2026-08-18 Sync WiFiManager from RFID_Access: correct the NTP poll interval
    The header comment on secsSinceTimeSync() said ESP-IDF re-polls hourly. It does
    not: CONFIG_LWIP_SNTP_UPDATE_DELAY is 10800000 ms, three hours. A caller that
    hard-codes a two-hour staleness threshold on the old claim reports a healthy
    device as unreachable for a third of every cycle.
2026-09-17 Sync WiFiManager from RFID_Access: retry the saved network from the portal
    A device that booted while its saved network was down stayed in the setup
    portal until someone rejoined it. It now retries the saved network in the
    background and reboots once it can join. See lib/WiFiManager/README.md,
    "Leaving the portal".
